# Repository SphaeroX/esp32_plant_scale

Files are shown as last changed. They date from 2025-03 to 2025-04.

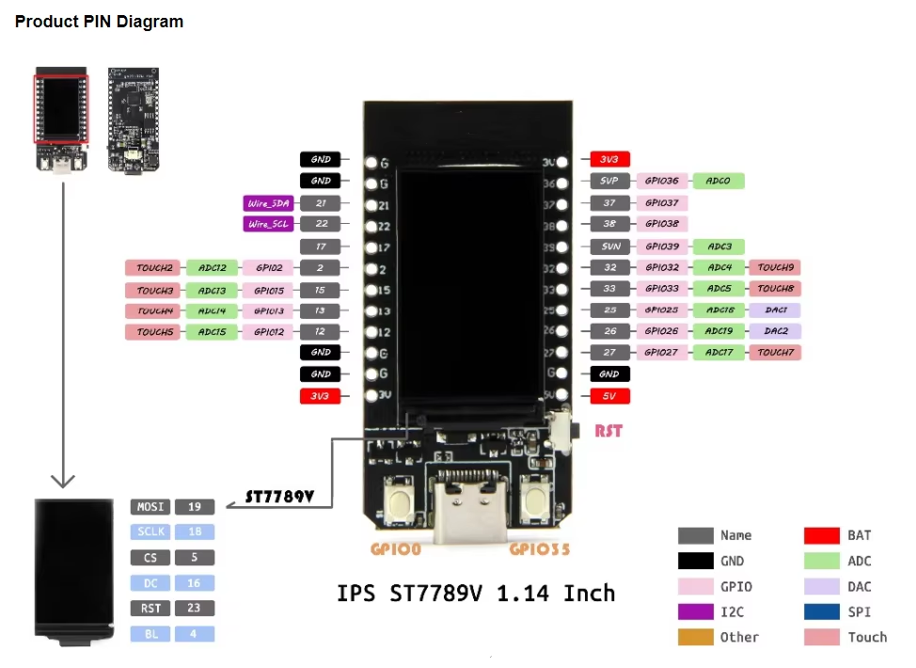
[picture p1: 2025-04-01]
controller.png

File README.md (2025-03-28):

# ESP32 Plant Monitoring Scale

## Project Description

This project implements a low-power plant monitoring system using an ESP32 microcontroller. It collects data such as plant weight and environmental parameters (temperature, humidity, air pressure) via HX711 and BME280 sensors. The ESP32 periodically wakes from deep sleep, performs measurements, sends data to ThingSpeak, and goes back to sleep. Power efficiency is prioritized for long-term, battery-powered operation.

The core functionality is the **detection of weight stagnation**, which indicates that the plant is no longer absorbing water – a sign that watering may be necessary.

---

## Features

- ESP32 with deep sleep and OTA update support
- Weight measurement with HX711 + load cell
- Environmental sensing with BME280
- EEPROM-persistent calibration and tare
- Detection of weight stagnation to estimate plant dryness
- Data upload to ThingSpeak
- First-boot setup via Serial Monitor

---

## Stagnation Detection

The system uses a custom algorithm to determine when watering is needed based on weight stagnation:

- Each time the device wakes up, the current weight is added to a **rolling buffer** of the last 7 measurements (`HISTORY_SIZE`).
- After an initial phase of 3 measurements (`IGNORE_FIRST_READINGS`), the system evaluates how often the weight has **decreased** between successive readings.
- A drop is only considered valid if the weight difference exceeds **1.3 grams** (`VALID_DROP_THRESHOLD`).
- If **fewer than 3 valid drops** (`MIN_VALID_DROPS`) are found in the history, it assumes that the weight has stagnated — and thus `wateringNeeded = true`.
- If sufficient drops are found, `wateringNeeded` is reset to `false`.

This approach helps to avoid false positives due to measurement noise or temporary load changes.

---

## Hardware Setup

| Component | Description |
|---|---|
| ESP32 | Preferably LILYGO® TTGO T-Display |
| HX711 | Load cell amplifier |
| Load Cell | 5 kg recommended or whatever u need |
| BME280 | I²C sensor for temperature/humidity |
| LiPo Battery | Power supply |

GPIO configuration:

| Function | Pin |
|---|---|
| HX711 DOUT | GPIO 32 |
| HX711 SCK | GPIO 33 |
| I²C SDA | GPIO 26 |
| I²C SCL | GPIO 27 |
| Battery Read | GPIO 34 |

---

## Setup Instructions

1. **Clone the Repository**:
```bash
git clone <your-repo-url>
```

2. **Configure Credentials**:
   - Copy `cred_example.cpp` to `cred.cpp`
   - Fill in your Wi-Fi and ThingSpeak credentials
   - Place it in the `src` folder

3. **Flash to ESP32** using Arduino IDE or PlatformIO

4. **Initial Setup (First Boot)**:
   - Open Serial Monitor (115200 baud)
   - Press any key within 10 seconds to open the setup menu
   - Follow instructions to:
     - Calibrate the scale
     - Apply tare (set zero)

---

## Data Upload (ThingSpeak)

Each cycle, the following data is sent to ThingSpeak:

| Field | Description |
|---|---|
| Field 1 | Weight in grams |
| Field 2 | Temperature (°C) |
| Field 3 | Humidity (%) |
| Field 4 | Air pressure (hPa) |
| Field 5 | Watering alert (0 = no, 1 = yes)  |
| Field 6 | Battery voltage (V) |

---

## Power Management

Before entering deep sleep:

- Sensors are powered down
- Serial, I²C, Bluetooth, and Wi-Fi are disabled
- RTC memory is used to retain weight history and status flags
- Wake-up is set using a timer (default: 900 seconds)

---

## Enclosure

STL and CAD files for 3D printing the enclosure are located in the `stl` directory.

---

## Planned Features

- BLE configuration interface (active during first 30 seconds after boot)
- Smartphone app for:
  - Real-time status
  - Alert notifications
  - Configuration of thresholds and Wi-Fi settings

---

## Contributing

Pull requests and suggestions are welcome. Please open an issue for bug reports or feature ideas.

---

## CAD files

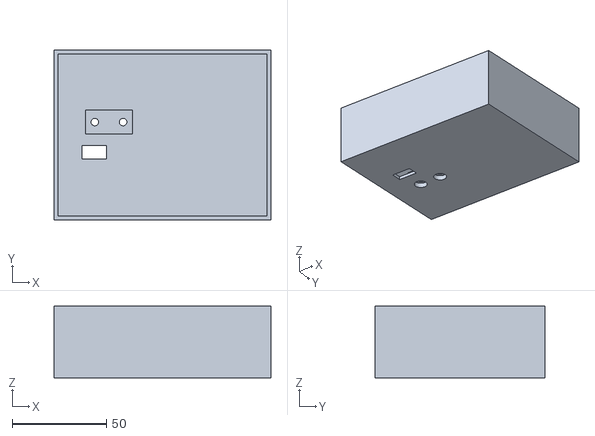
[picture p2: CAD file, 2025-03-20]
stl/top.stl
115.0 x 90.0 x 38.0

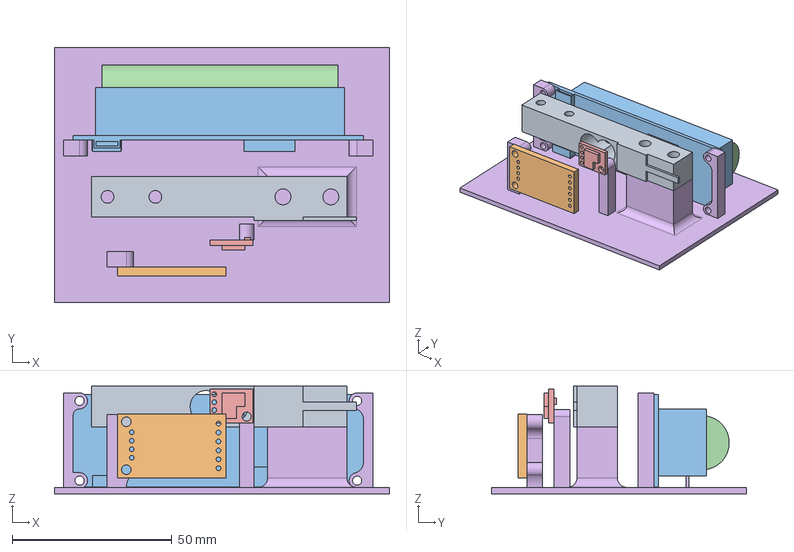
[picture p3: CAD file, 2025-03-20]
stl/cad.step
105.0 x 80.0 x 33.7 mm
waegezelle
HX711
ESP32 18650 Battery Akku
BME280 temparatursensor sensor
Gehäuse

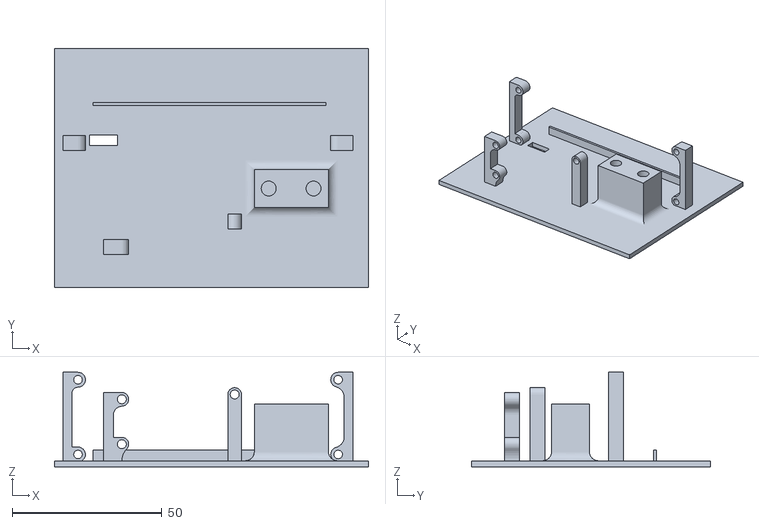
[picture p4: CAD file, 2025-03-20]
stl/bottom.stl
105.0 x 80.0 x 31.6

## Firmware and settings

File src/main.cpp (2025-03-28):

#include <Arduino.h>
#include <EEPROM.h>
#include "cred.h"
#include "config.h"
#include "sensors.h"
#include "network.h"
#include "menu.h"
#include "eeprom_handler.h"
#include <Wire.h>
#include <ArduinoOTA.h>

// Track if this is the first boot since power-on
RTC_DATA_ATTR bool firstBoot = true;

// Global flag for stagnation detection
bool stagnationDetected = false;

// Function to read battery voltage
float readBatteryVoltage()
{
  // Calculate battery voltage
  float batteryVoltage = (float)(analogRead(PIN_BAT_VOLT)) * 3600 / 4095 * 2;

  if (batteryVoltage > 4300)
  {
    return 0;
  }
  else
  {
    return batteryVoltage;
  }
}

void setupOTA()
{
  ArduinoOTA.setHostname("esp32-plant-scale");
  ArduinoOTA.onStart([]()
                     { Serial.println("Start OTA update..."); });
  ArduinoOTA.onEnd([]()
                   { Serial.println("\nOTA update complete."); });
  ArduinoOTA.onProgress([](unsigned int progress, unsigned int total)
                        { Serial.printf("OTA Progress: %u%%\r", (progress / (total / 100))); });
  ArduinoOTA.onError([](ota_error_t error)
                     {
      Serial.printf("OTA Error[%u]: ", error);
      if (error == OTA_AUTH_ERROR) Serial.println("Auth Failed");
      else if (error == OTA_BEGIN_ERROR) Serial.println("Begin Failed");
      else if (error == OTA_CONNECT_ERROR) Serial.println("Connect Failed");
      else if (error == OTA_RECEIVE_ERROR) Serial.println("Receive Failed");
      else if (error == OTA_END_ERROR) Serial.println("End Failed"); });
  ArduinoOTA.begin();
}

void setup()
{
  Serial.begin(115200);
  delay(500);

  // Initialize EEPROM
  EEPROM.begin(EEPROM_SIZE);
  delay(100);

  pinMode(PIN_BAT_VOLT, INPUT);

  // Load calibration data from EEPROM
  loadCalibrationData();

  // Initialize network and connect to WiFi
  initializeNetwork();
  connectToWiFi();

  // Initialize sensors
  initializeSensors();

  // Check for menu activation (10 seconds)
  if (firstBoot)
  {
    Serial.println("Press any key for menu (10 seconds)...");
    unsigned long startTime = millis();
    bool menuActivated = false;
    while (millis() - startTime < 10000)
    {
      ArduinoOTA.handle(); // OTA-Update Ready

      if (Serial.available() > 0)
      {
        menuActivated = true;
        break;
      }
    }
    if (menuActivated)
    {
      while (Serial.available() > 0)
      {
        Serial.read();
      }
      menuLoop();
    }
  }
}

void loop()
{
  // Power up sensors
  powerUpSensors();

  if (waitForScaleReady(5000))
  {
    // Get calibrated weight reading
    float weight = getFilteredWeight();

    // Add to history and check for stagnation
    addWeightToHistory(weight);
    checkForStagnation();

    // Read sensor values from BME280
    float temperature = getTemperature();
    float humidity = getHumidity();
    float pressure = getPressure();
    bool needsWatering = isWateringNeeded();
    float batteryVoltage = readBatteryVoltage();

    Serial.print("Weight: ");
    Serial.print(weight, 1);
    Serial.println(" g");

    Serial.print("Measured temperature: ");
    Serial.print(temperature, 1);
    Serial.println(" °C");

    Serial.print("Needs watering: ");
    Serial.println(needsWatering, 1);

    Serial.print("Battery Voltage: ");
    Serial.print(batteryVoltage, 1);
    Serial.println(" V");

    // Send data to ThingSpeak using network module
    sendSensorData(weight, temperature, humidity, pressure, batteryVoltage, needsWatering);
  }
  else
  {
    Serial.println("Error: HX711 not ready!");
  }

  Serial.println("Turning off sensors...");
  powerDownSensors();

  Serial.println("Entering deep sleep mode...");
  delay(500);

  // Disconnect network
  disconnectNetwork();

  Serial.end();
  Wire.end();
  btStop();
  delay(100);

  // Enable lowest power consumption mode
  esp_sleep_pd_config(ESP_PD_DOMAIN_RTC_PERIPH, ESP_PD_OPTION_AUTO);
  esp_sleep_pd_config(ESP_PD_DOMAIN_RTC_SLOW_MEM, ESP_PD_OPTION_AUTO); // AUTO due to RTC_DATA_ATTR
  esp_sleep_pd_config(ESP_PD_DOMAIN_RTC_FAST_MEM, ESP_PD_OPTION_AUTO); // AUTO due to RTC_DATA_ATTR
  esp_sleep_pd_config(ESP_PD_DOMAIN_XTAL, ESP_PD_OPTION_OFF);

  firstBoot = false;

  esp_sleep_enable_timer_wakeup(SLEEP_TIME * 1000000ULL);
  esp_deep_sleep_start();
}

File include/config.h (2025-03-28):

#ifndef CONFIG_H
#define CONFIG_H

// GPIO Pin Definitions
#define DOUT_PIN 32     // HX711 data pin
#define SCK_PIN 33      // HX711 clock pin
#define SDA_PIN 26      // I²C SDA pin
#define SCL_PIN 27      // I²C SCL pin
#define PIN_BAT_VOLT 34 // Battery Pin for T-Display ESP32 WiFi

// Deep Sleep Configuration
#define SLEEP_TIME 900 // Deep sleep time in seconds (900 = 15 minutes)

// EEPROM Configuration
#define EEPROM_SIZE 8       // EEPROM size in bytes
#define EEPROM_TARE_ADDR 0  // EEPROM address for tare offset (4 bytes)
#define EEPROM_CALIB_ADDR 4 // EEPROM address for calibration factor (4 bytes)

// Measurement Settings
#define HISTORY_SIZE 7          // Number of stored weight values for evaluation
#define IGNORE_FIRST_READINGS 3 // Number of initial measurements to ignore after startup
#define NUM_MEASUREMENTS 10     // Number of measurements per weight value

// Stagnation Detection Settings
#define MIN_VALID_DROPS 3        // Minimum number of valid drops required from HISTORY_SIZE
#define VALID_DROP_THRESHOLD 1.3 // Minimum drop (in grams) to consider a value valid

#endif // CONFIG_H

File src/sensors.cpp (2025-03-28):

#include "sensors.h"
#include <Wire.h>
#include <EEPROM.h>
#include "config.h"

// Define the global variables declared in the header
HX711 scale;
Adafruit_BME280 bme;
float calibrationFactor = 1.0;
float tareOffset = 0.0;
bool wateringNeeded = false;

// Weight history variables
RTC_DATA_ATTR float weightHistory[HISTORY_SIZE] = {0};
RTC_DATA_ATTR int historyIndex = 0;
RTC_DATA_ATTR int readingCount = 0;

// Stagnation detection variables
RTC_DATA_ATTR float referenceAvgWeight = 0.0;
RTC_DATA_ATTR bool stagnationMode = false;
RTC_DATA_ATTR bool isFirstEvaluation = true;

void initializeSensors()
{
  // Initialize custom I²C pins
  Wire.begin(SDA_PIN, SCL_PIN);

  // Initialize BME280 sensor (I2C address 0x76)
  if (!bme.begin(0x76))
  {
    Serial.println("Could not find a valid BME280 sensor, check wiring!");
    while (1)
    {
      delay(1000);
    }
  }

  // Initialize HX711
  scale.begin(DOUT_PIN, SCK_PIN);
  scale.set_scale(calibrationFactor);
  scale.set_offset(tareOffset);
  Serial.println("HX711 started");
}

void loadCalibrationData()
{
  // Load stored calibration factor from EEPROM
  EEPROM.get(EEPROM_CALIB_ADDR, calibrationFactor);
  if (isnan(calibrationFactor) || calibrationFactor == 0)
  {
    calibrationFactor = 1.0;
  }
  Serial.print("Stored calibration factor: ");
  Serial.println(calibrationFactor, 6);

  // Load and apply stored tare offset
  EEPROM.get(EEPROM_TARE_ADDR, tareOffset);
  if (isnan(tareOffset))
  {
    tareOffset = 0.0;
  }
  Serial.print("Stored tare offset: ");
  Serial.println(tareOffset, 3);

  // Apply loaded values to the scale
  scale.set_scale(calibrationFactor);
  scale.set_offset(tareOffset);
}

bool waitForScaleReady(unsigned long timeoutMillis)
{
  unsigned long startTime = millis();
  while (millis() - startTime < timeoutMillis)
  {
    if (scale.is_ready())
    {
      return true;
    }
    delay(10);
  }
  return false;
}

float getFilteredWeight()
{
  return scale.get_units(NUM_MEASUREMENTS);
}

void addWeightToHistory(float weight)
{
  weightHistory[historyIndex] = weight;
  historyIndex = (historyIndex + 1) % HISTORY_SIZE;
  readingCount++;
}

void checkForStagnation()
{
  // Check if enough data is available
  if (readingCount < (IGNORE_FIRST_READINGS + HISTORY_SIZE))
  {
    Serial.println("Initialization phase: " + String(readingCount) + "/" +
                   String(IGNORE_FIRST_READINGS + HISTORY_SIZE));
    return;
  }

  int validCount = 0;
  // Loop through the weight history and count valid drops
  for (int i = 1; i < HISTORY_SIZE; i++)
  {
    // Check if the previous measurement is at least 1g higher than the current measurement
    if ((weightHistory[i - 1] - weightHistory[i]) >= VALID_DROP_THRESHOLD)
    {
      validCount++;
    }
  }

  if (validCount >= MIN_VALID_DROPS)
  {
    wateringNeeded = false;
    Serial.println("No stagnation detected: " + String(validCount) + " valid drops.");
  }
  else
  {
    wateringNeeded = true;
    Serial.println("Stagnation detected: Only " + String(validCount) + " valid drops.");
  }
}

void calibrateScale()
{
  Serial.println("Calibration mode activated.");
  Serial.println("Ensure the scale is empty. Press any key when ready.");
  while (Serial.available() == 0)
  {
    // Waiting for user input
  }
  while (Serial.available() > 0)
  {
    Serial.read();
  }

  // Reset scale factor and tare the scale
  scale.set_scale();
  scale.tare();
  Serial.println("Scale set to zero. Now place a known weight on the scale and enter the weight in grams.");
  while (Serial.available() == 0)
  {
    // Waiting for user input
  }
  float knownWeight = Serial.parseFloat();
  while (Serial.available() > 0)
  {
    Serial.read();
  }

  if (knownWeight <= 0)
  {
    Serial.println("Invalid input for known weight.");
    return;
  }
  else
  {
    Serial.print("Known weight: ");
    Serial.print(knownWeight);
    Serial.println(" g");
  }

  // Wait for the reading to stabilize
  delay(1000);
  float reading = scale.get_units(10);
  Serial.print("Measured weight with known load: ");
  Serial.println(reading, 3);

  // Calculate calibration factor: (measured reading) / (known weight)
  calibrationFactor = reading / knownWeight;
  scale.set_scale(calibrationFactor);
  EEPROM.put(EEPROM_CALIB_ADDR, calibrationFactor);
  EEPROM.commit();

  Serial.print("Calibration completed. New calibration factor: ");
  Serial.println(calibrationFactor, 6);
}

void setTare()
{
  Serial.println("Taring... Please remove any load from the scale.");
  if (waitForScaleReady(5000))
  {
    // Get the current raw reading (without calibration factor)
    long rawReading = scale.read_average(10);
    // Store this value as the offset
    scale.set_offset(rawReading);
    // Save the offset for future use
    tareOffset = rawReading;
    EEPROM.put(EEPROM_TARE_ADDR, tareOffset);
    EEPROM.commit();
    Serial.print("Taring completed. New offset saved: ");
    Serial.println(tareOffset, 3);
  }
  else
  {
    Serial.println("Error: HX711 not ready!");
  }
}

void showSensorData()
{
  Serial.println("\n=== Sensor Data ===");
  if (waitForScaleReady(5000))
  {
    // Get raw reading from the load cell (already averaged)
    float rawValue = getFilteredWeight();
    // Read temperature, humidity, and pressure from BME280
    float temperature = getTemperature();
    float humidity = getHumidity();
    float pressure = getPressure();

    Serial.print("HX711 scale.get_units(5): ");
    Serial.println(scale.get_units(5), 3);

    Serial.print("Load cell raw data (average): ");
    Serial.print(rawValue, 3);
    Serial.println(" (calibrated units)");

    Serial.print("Temperature: ");
    Serial.print(temperature, 2);
    Serial.println(" °C");

    Serial.print("Humidity: ");
    Serial.print(humidity, 2);
    Serial.println(" %");

    Serial.print("Pressure: ");
    Serial.print(pressure, 2);
    Serial.println(" hPa");
  }
  else
  {
    Serial.println("Error: HX711 not ready!");
  }
  Serial.println("=== End of Sensor Data ===\n");
}

void powerUpSensors()
{
  scale.power_up();

  bme.setSampling(Adafruit_BME280::MODE_NORMAL,
                  Adafruit_BME280::SAMPLING_X1, // Temperature
                  Adafruit_BME280::SAMPLING_X1, // Pressure
                  Adafruit_BME280::SAMPLING_X1, // Humidity
                  Adafruit_BME280::FILTER_OFF,
                  Adafruit_BME280::STANDBY_MS_0_5);

  delay(500);
}

void powerDownSensors()
{
  scale.power_down();

  bme.setSampling(Adafruit_BME280::MODE_SLEEP,
                  Adafruit_BME280::SAMPLING_NONE, // Temperature
                  Adafruit_BME280::SAMPLING_NONE, // Pressure
                  Adafruit_BME280::SAMPLING_NONE, // Humidity
                  Adafruit_BME280::FILTER_OFF,
                  Adafruit_BME280::STANDBY_MS_0_5);
}

// Sensor data getters
float getTemperature()
{
  return bme.readTemperature();
}

float getHumidity()
{
  return bme.readHumidity();
}
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
